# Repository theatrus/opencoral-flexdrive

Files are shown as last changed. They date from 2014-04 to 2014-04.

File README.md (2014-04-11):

# OpenCoral FlexDrive High Current LED Driver

LM3404(HV) based dual LED driver with optional MCU supervision / dimming
support.

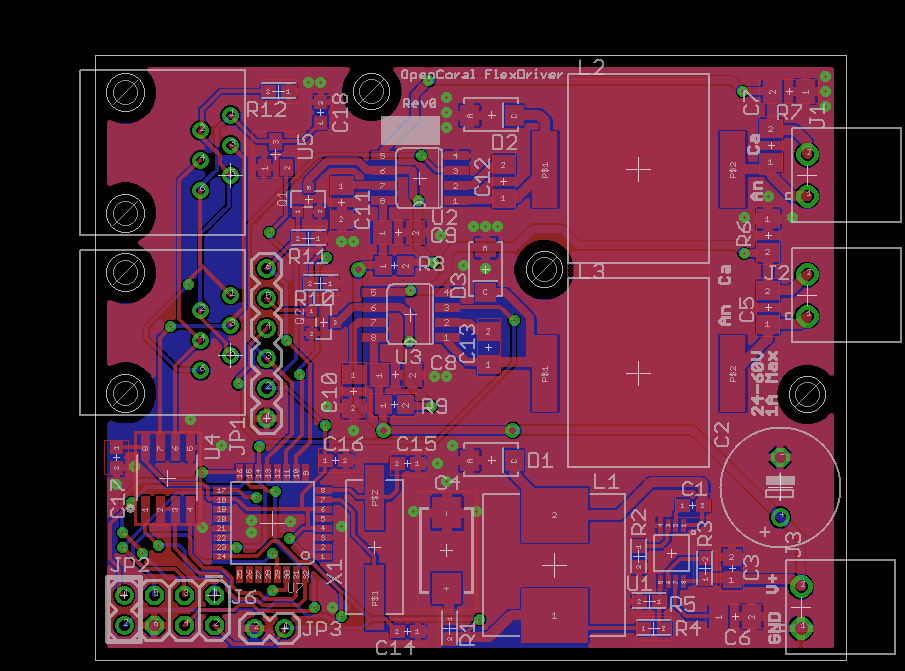
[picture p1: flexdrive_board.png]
product


# Features

 * Dual LM3404HV drivers and all power switching circuitry.
 * Runs on up to 60V input, 24-48VDC suggested.
 * Up to 1.5A per LED chain
 * On board MCU and power supply for dimming control of each channel
   (ATmega8)
 * RS485 transceiver and two RJ-12 jacks for control signals from a
   controller.
 * MCU is optional, dimming control can be done via external pins (PWM)

# License

CC-SA-NC 3.0.

See LICENSE.txt

# Design Status

This design was built and is in operation.

## Boards

Available on OSHPark:
http://oshpark.com/shared_projects/ymYU4l9N

# Files available

The original design is available as Eagle 6.x (XML-based) design
files, in the eagle/ directory.

Gerber files from the Eagle board file are made available in the
gerber/ directory.

Schematic PDF is available in the root of this repository.

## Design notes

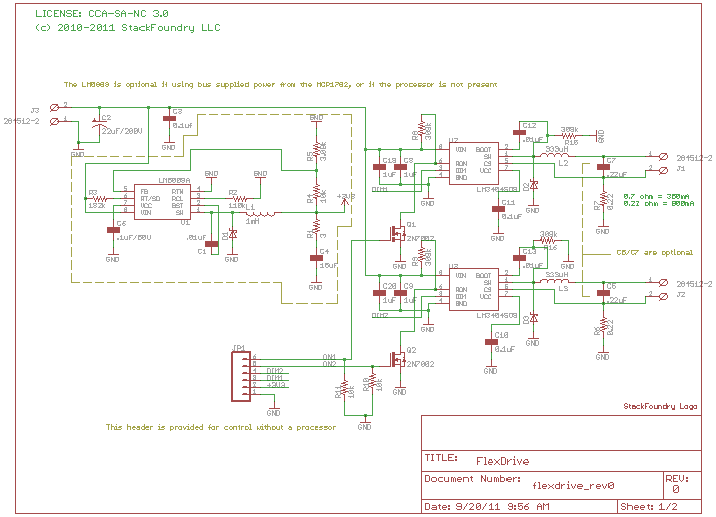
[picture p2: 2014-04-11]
fd_sch.png

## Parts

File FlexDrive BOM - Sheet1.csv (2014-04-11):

Manufacturer | Part | Description | Ref Desgs | Qty | Use | Budgetary Cost | Budgetary Cost Ext | Bought From
PCB + Mechanical
PCB |  |  |  | 1 |  | $0.00 | $0.00
 |  |  |  |  |  |  | $0.00
Actives |  |  |  |  |  |  | $0.00
National | LM3404HVMA | LED Driver |  | 2 |  | $2.26 | $4.52
National | LM5009MM/NOPB | Buck Converter |  | 1 |  | $3.72 | $3.72
Atmel | ATMEGA88PA-AU | Microcontroller |  | 1 |  | $2.50 | $2.50
TI | SN65HVD12DG4 | RS485 Driver |  | 1 |  | $2.10 | $2.10
Abracon | ABLS-8.000MHZ-B2-T | CRYSTAL 8.000MHZ 18PF SMD |  | 1 |  | $0.56 | $0.56
 |  |  |  |  |  |  | $0.00
Passives |  |  |  |  |  |  | $0.00
Kemet | C1206C104K5RACTU | CAP 0.1UF 50VDC X7R 10% SMD 1206 |  | 3 |  | $0.03 | $0.10
Kemet | C1206C103K5RACTU | CAP 0.01UF 50VDC X7R 10% SMD 1206 |  | 2 |  | $0.04 | $0.07
Taiyo-Yuden | HMK316B7105KL-T | CAP CER 1UF 100V X7R 1206 |  | 4 |  | $0.31 | $1.24
TDK | C3216X7R2A224K | CAP CER .22UF 100V X7R 10% 1206 |  | 2 |  | $0.18 | $0.36
Diodes Inc | B1100-13-F | DIODE SCHOTTKY 100V 1A SMA |  | 3 |  | $0.34 | $1.02
Yageo | PT1206FR-070R22L | RES 0.22 OHM 0.25W 1% 1206 SMD |  | 2 |  | $0.13 | $0.25
Taiyo-Yuden | HMK212B7104KG-T | CAP CER .10UF 100V X7R 0805 |  | 1 |  | $0.26 | $0.26
StackPole | RMCF0603FT3K09 | RES 3.09K OHM 1/10W 1% 0603 SMD |  | 1 |  | $0.04 | $0.04
Panasonic | ERJ-3EKF1103V | RES 110K OHM 1/10W 1% 0603 SMD |  | 1 |  | $0.04 | $0.04
Panasonic |  | RES 10K OHM 1/10W 1% 0603 SMD |  | 1 |  | $0.04 | $0.04
Panasonic | ERJ-3EKF1823V | RES 182K OHM 1/10W 1% 0603 SMD |  | 1 |  | $0.04 | $0.04
AVX | TAJD156K025RNJ | CAP TANTALUM 15UF 25V 10% SMD |  | 1 |  | $0.74 | $0.74
Yageo | RC0603JR-073RL | RES 3.0 OHM 1/10W 5% 0603 SMD |  | 1 |  | $0.04 | $0.04
Coilcraft | DO5040H-334KLB | DO5040H Series High Current |  | 2 |  | $1.50 | $3.00
Coilcraft | MSS1246-105KLB | MSS1246-105KLB |  | 1 |  | $1.04 | $1.04
 |  |  |  |  |  |  | $0.00
Connectors |  |  |  |  |  |  | $0.00
Tyco | 284512-2 | TERM BLOCK HEADER 2POS R/A 3.5MM |  | 3 |  | $0.39 | $1.17 | DigiKey
Tyco | 284506-2 | TERM BLOCK PLUG 2POS 3.5MM |  | 3 |  | $0.77 | $2.31 | DigiKey
 |  |  |  |  |  |  | $0.00
 |  |  |  |  |  |  | $25.17
 |  |  |  |  |  | Price per LED (24LEDs) | $1.04875

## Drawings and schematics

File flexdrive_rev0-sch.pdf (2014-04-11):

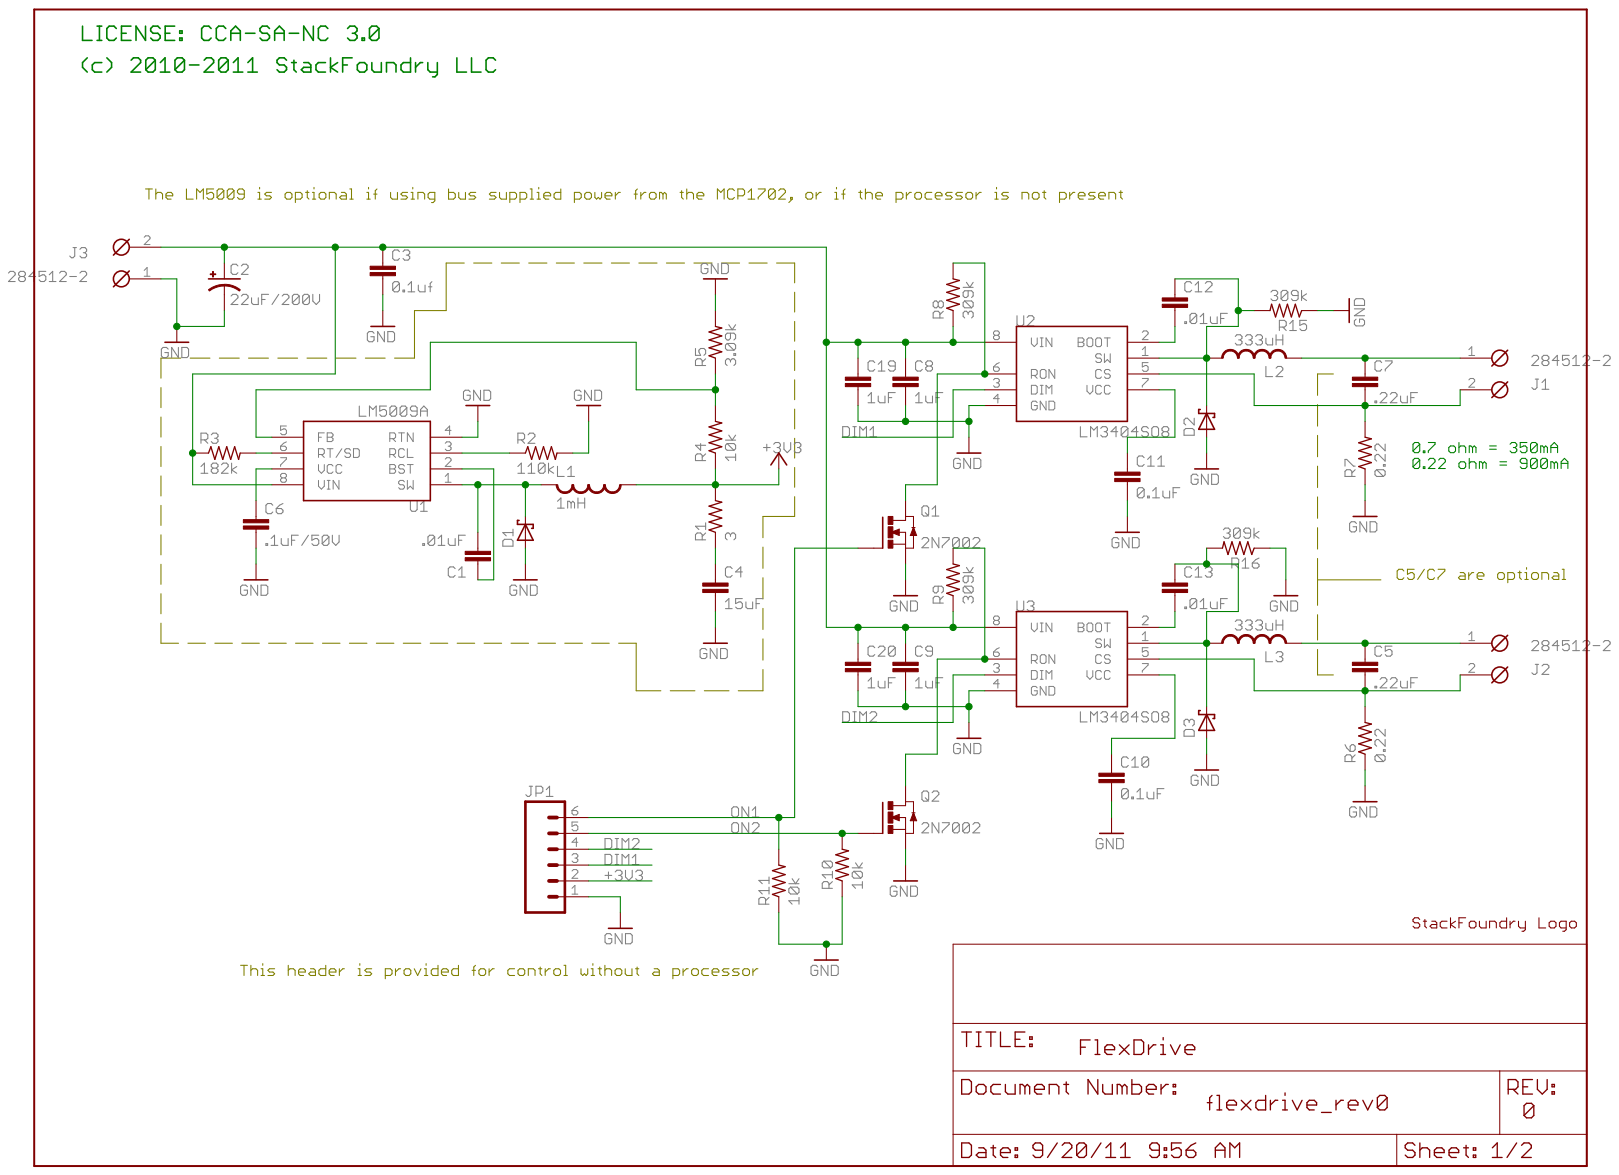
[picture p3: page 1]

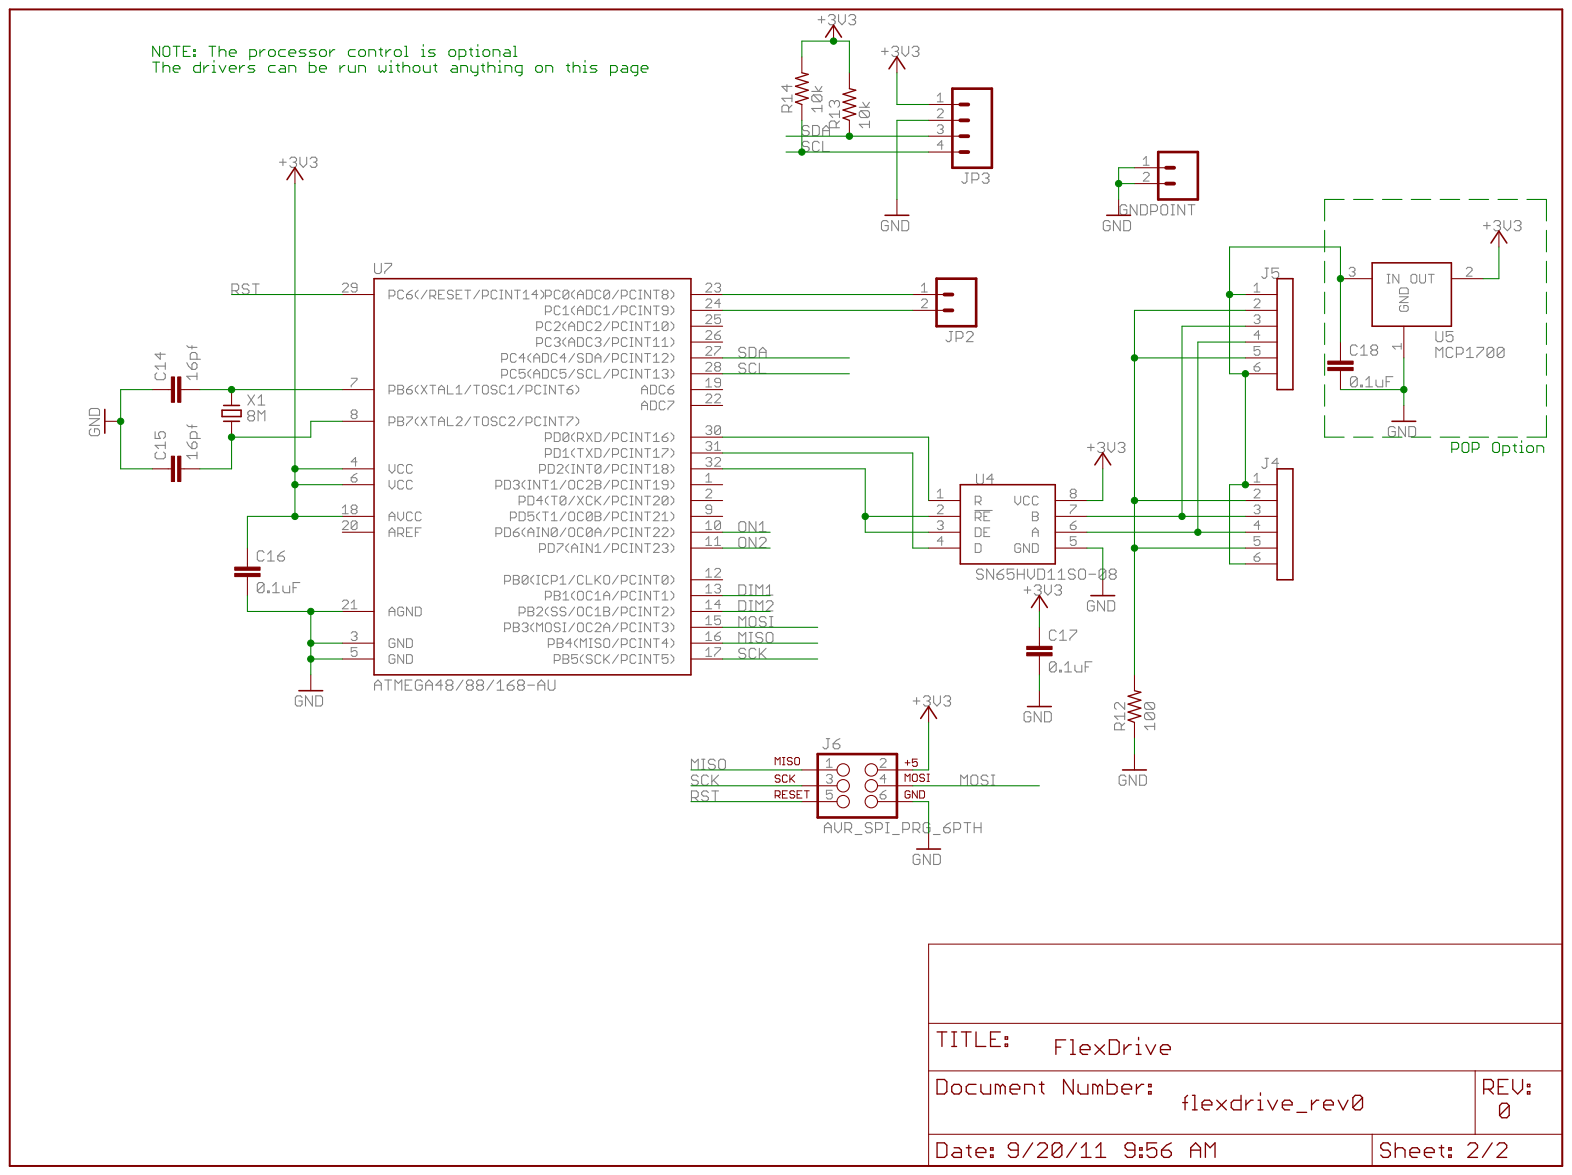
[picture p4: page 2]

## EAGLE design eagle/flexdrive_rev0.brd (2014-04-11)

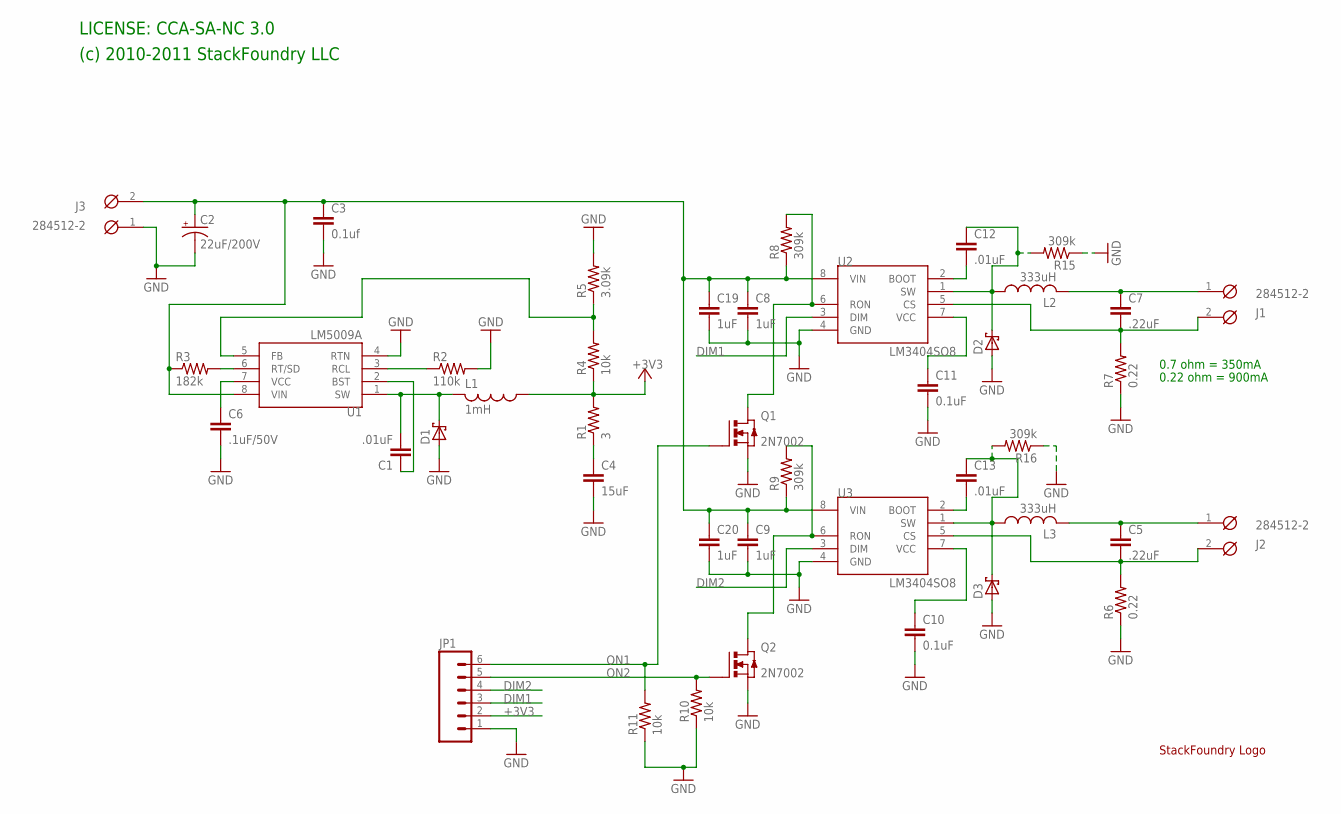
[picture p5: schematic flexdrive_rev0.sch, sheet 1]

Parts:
C1: .01uF; C0603
C2: 22uF/200V; E5-10,5
C3: 0.1uf; C0805
C4: 15uF; CT7343
C5, C7: .22uF; C1206
C6: .1uF/50V; C1206
C8, C9, C19, C20: 1uF; C1206
C10, C11: 0.1uF; C1206
C12, C13: .01uF; C1206
D1, D2, D3: SCHOTTKY-DIODESMA; SMA
J1, J2, J3: 284512-2
JP1: M06SIP; 1X06
L1: 1mH; MSS1246
L2, L3: 333uH; DO5040H
LOGO1: SFLOGO
Q1, Q2: 2N7002; SOT23
R1: 3; R0603
R2: 110k; R0603
R3: 182k; R0603
R4, R10, R11: 10k; R0603
R5: 3.09k; R0603
R6, R7: 0.22; R1206
R8, R9, R15, R16: 309k; R0805
U1: LM5009A; MSOP-8
U2, U3: LM3404SO8; SO08

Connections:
+3V3: JP1.2, L1.1, R1.2, R4.1; also elsewhere on the board
DIM1: JP1.3, U2.3 (DIM); also elsewhere on the board
DIM2: JP1.4, U3.3 (DIM); also elsewhere on the board
GND: C2.-, C3.2, C4.- (2), C6.2, C8.2, C9.2, C10.2, C11.2, C19.2, C20.2, D1.A, D2.A, D3.A, J3.1, JP1.1, Q1.2 (S), Q2.2 (S), R2.2, R5.2, R6.1, R7.1, R10.1, R11.1, R15.1, R16.1, U1.4 (RTN), U2.4 (GND), U3.4 (GND); also elsewhere on the board
unnamed: C2.+, C3.1, C8.1, C9.1, C19.1, C20.1, J3.2, R3.1, R8.1, R9.1, U1.8 (VIN), U2.8 (VIN), U3.8 (VIN)
unnamed: C1.2, D1.C, L1.2, U1.1 (SW)
unnamed: C1.1, U1.2 (BST)
unnamed: C4.+ (1), R1.1
unnamed: R2.1, U1.3 (RCL)
unnamed: R3.2, U1.6 (RT/SD)
unnamed: C6.1, U1.7 (VCC)
unnamed: R4.2, R5.1, U1.5 (FB)
unnamed: C12.1, D2.C, L2.P$1 (1), R15.2, U2.1 (SW)
unnamed: C13.1, D3.C, L3.P$1 (1), R16.2, U3.1 (SW)
unnamed: C7.1, J1.1, L2.P$2 (2)
unnamed: C5.1, J2.1, L3.P$2 (2)
unnamed: C7.2, J1.2, R7.2, U2.5 (CS)
unnamed: C10.1, U3.7 (VCC)
unnamed: C11.1, U2.7 (VCC)
unnamed: C13.2, U3.2 (BOOT)
unnamed: C12.2, U2.2 (BOOT)
unnamed: C5.2, J2.2, R6.2, U3.5 (CS)
unnamed: Q1.3 (D), R8.2, U2.6 (RON)
unnamed: Q2.3 (D), R9.2, U3.6 (RON)
ON1: JP1.6, Q1.1 (G), R11.2; also elsewhere on the board
ON2: JP1.5, Q2.1 (G), R10.2; also elsewhere on the board

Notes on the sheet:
0.7 ohm = 350mA
0.22 ohm = 900mA
LICENSE: CCA-SA-NC 3.0
(c) 2010-2011 StackFoundry LLC

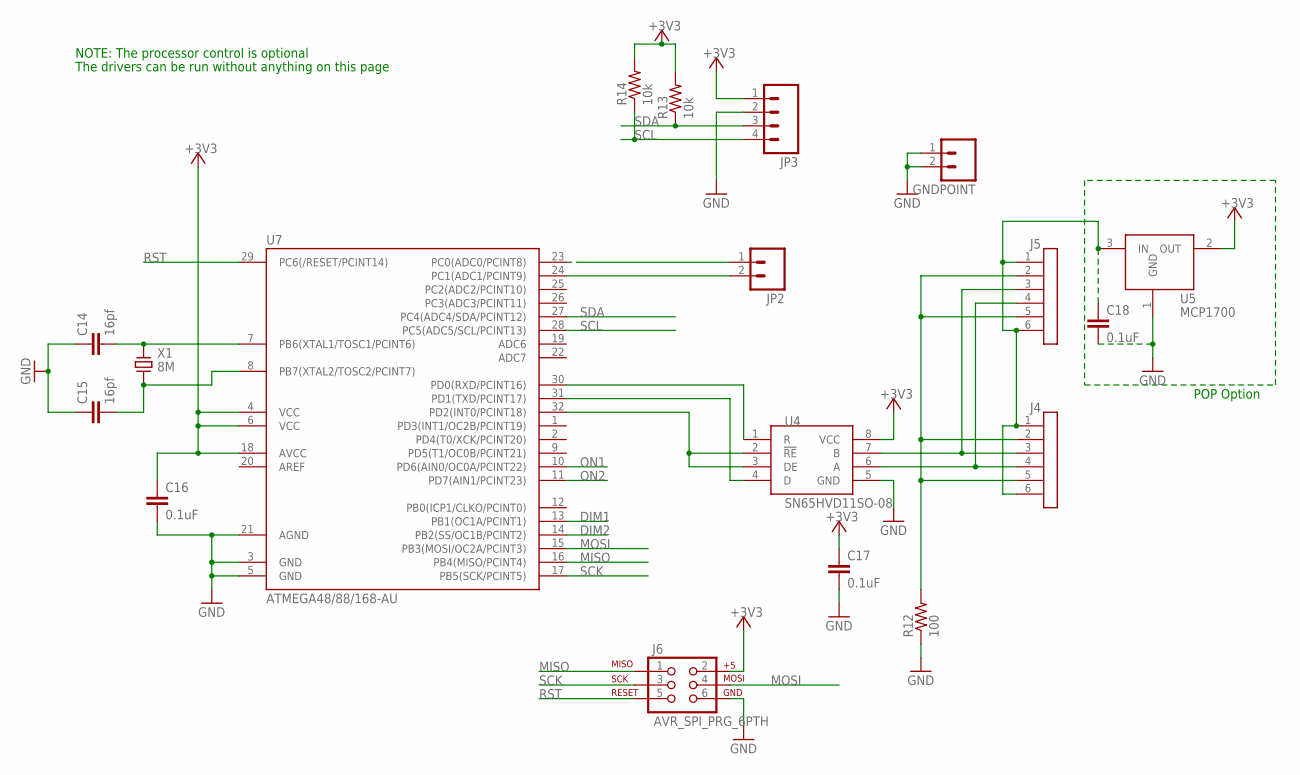
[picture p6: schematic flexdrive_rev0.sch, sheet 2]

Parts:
C14, C15: 16pf; C0603
C16, C17, C18: 0.1uF; C0603
GNDPOINT: M02PTH; 1X02
J4, J5: RJ12; A-2004-RJ12
J6: AVR_SPI_PRG_6PTH; 2X3
JP2: M02PTH; 1X02
JP3: M04PTH; 1X04
R12: 100; R0603
R13, R14: 10k; R0603
U4: SN65HVD11SO-08; SO-08
U5: MCP1700; SOT23
U7: ATMEGA48/88/168-AU; TQFP32-08
X1: 8M; HCM49

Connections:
+3V3: C16.1, C17.1, J6.2, JP3.1, R13.2, R14.2, U4.8 (VCC), U5.2 (OUT), U7.4 (VCC), U7.6 (VCC), U7.18 (AVCC); also elsewhere on the board
DIM1: U7.13 (PB1(OC1A/PCINT1)); also elsewhere on the board
DIM2: U7.14 (PB2(SS/OC1B/PCINT2)); also elsewhere on the board
GND: C14.1, C15.1, C16.2, C17.2, C18.2, GNDPOINT.1, GNDPOINT.2, J6.6, JP3.2, R12.1, U4.5 (GND), U5.1 (GND), U7.3 (GND), U7.5 (GND), U7.21 (AGND); also elsewhere on the board
MISO: J6.1, U7.16 (PB4(MISO/PCINT4))
MOSI: J6.4, U7.15 (PB3(MOSI/OC2A/PCINT3))
unnamed: U4.2 (!RE), U4.3 (DE), U7.32 (PD2(INT0/PCINT18))
unnamed: C14.2, U7.7 (PB6(XTAL1/TOSC1/PCINT6)), X1.P$1
unnamed: C15.2, U7.8 (PB7(XTAL2/TOSC2/PCINT7)), X1.P$2
unnamed: U4.1 (R), U7.30 (PD0(RXD/PCINT16))
unnamed: U4.4 (D), U7.31 (PD1(TXD/PCINT17))
unnamed: J4.3, J5.3, U4.7 (B)
unnamed: J4.4, J5.4, U4.6 (A)
unnamed: J4.2, J4.5, J5.2, J5.5, R12.2
unnamed: C18.1, J4.1, J4.6, J5.1, J5.6, U5.3 (IN)
unnamed: JP2.1, U7.23 (PC0(ADC0/PCINT8))
unnamed: JP2.2, U7.24 (PC1(ADC1/PCINT9))
ON1: U7.10 (PD6(AIN0/OC0A/PCINT22)); also elsewhere on the board
ON2: U7.11 (PD7(AIN1/PCINT23)); also elsewhere on the board
RST: J6.5, U7.29 (PC6(/RESET/PCINT14))
SCK: J6.3, U7.17 (PB5(SCK/PCINT5))
SCL: JP3.4, R14.1, U7.28 (PC5(ADC5/SCL/PCINT13))
SDA: JP3.3, R13.1, U7.27 (PC4(ADC4/SDA/PCINT12))

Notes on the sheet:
POP Option
NOTE: The processor control is optional
The drivers can be run without anything on this page

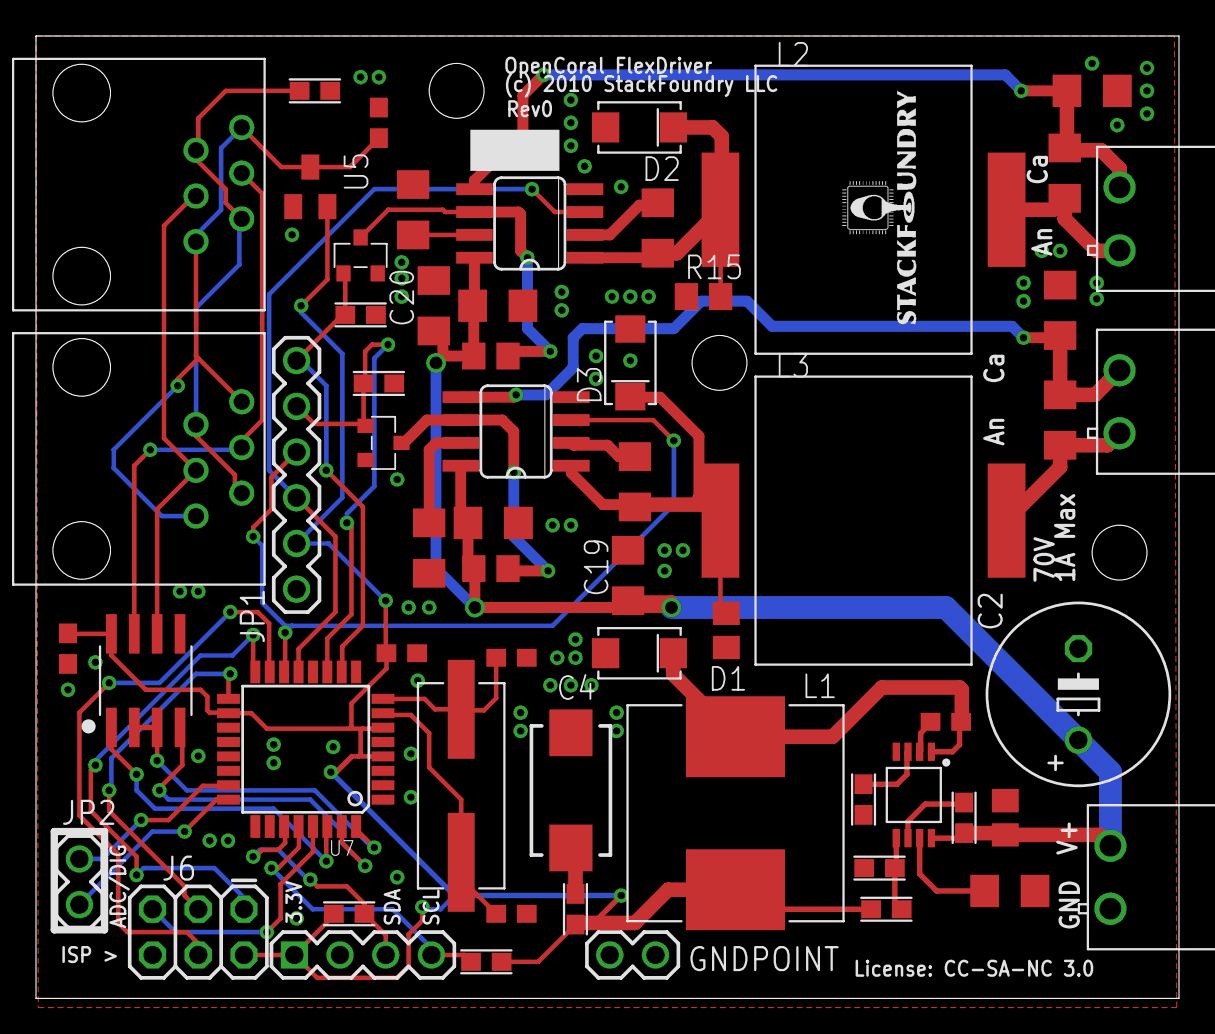
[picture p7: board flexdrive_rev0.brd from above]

Board: 2 copper layers, 63.5 x 53.5 mm, 62 parts (0 on the bottom side), 43 nets.

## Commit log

2014-04-11 OpenCoral FlexDrive
    [flexdrive_rev0.brd, flexdrive_rev0.sch]
2014-04-11 Add BOM
    [FlexDrive BOM - Sheet1.csv, FlexDrive BOM.ods, FlexDrive BOM.xlsx]

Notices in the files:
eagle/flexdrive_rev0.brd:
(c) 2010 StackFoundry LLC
